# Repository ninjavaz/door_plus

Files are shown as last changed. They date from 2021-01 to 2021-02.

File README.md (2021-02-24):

Finished code for Door+ module. It's develop branch from private project repository.

Copyright (C) 2021 Door+ <d1n22@onet.pl><br>
This file is part of the Door+ project.<br>
The Door+ project can not be copied and/or distributed without the express<br>
permission of author Dominik Nuszkiewicz <d1n22@onet.pl>.<br>

# Door+

## Table of contents
* [General info](#general-info)
* [Technologies](#technologies)
* [Additional libraries](#libraries)
* [Components](#components)
* [Photos](#photos)

## General info
Door+ is automatic, contactless door module with IoT elements based on ESP32. It was made for engineering project on Warsaw University of Technology. It was built with MQTT server - https://hivemq.com
Physical module has a few functions. Main of these are:

1. Contactless opening and closing doors with ultrasonic motion sensor.
2. Counting people in the room - based on motion sensor too.
3. Remote communication provided by MQTT server and connected application of smartphone.

## Technologies
I used:
* https://hivemq.com as MQTT server
* MQTT Dash - app to send messages to MQTT
* PlatformIO IDE Ver 2.2.1
* Visual Studio Code Ver 1.52.1
* Tinkercad to create 3D printings

## Additional libraries
* PubSubClient 
* ESPAsyncWiFiManager
* ESPASyncWebServer
* Adafruit GFX Library
* AsyncTCP
* PubSubClient

## Components
Project was created with:
* Wemos D1 UNO R32 ESP32 WIFI Bluetooth
* Motion sensor HC-SR04 x2
* OLED monitor( SSD1306, 128x64px)
* Electric actuator LA10 500N 13mm/s, 12V, length max = 15 cm
* Power supply 12V for actuator
* Relays module with 2 canals 5V 10A/250VAC
* Power supply 9V for Wemos
* 3D Printings
* some typical cables and mini breadboard

## Photos

<p align="center">
  The main part with ESP32<br><br>
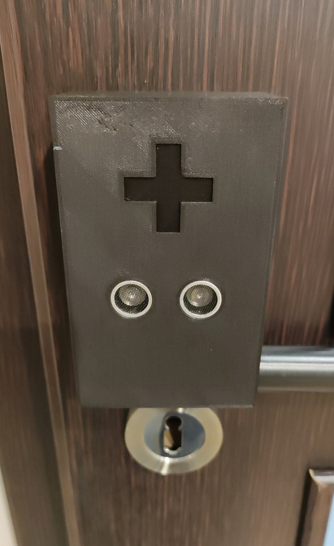
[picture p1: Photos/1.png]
  <br><br>
</p>
  
<p align="center">
  Back part with OLED<br><br>
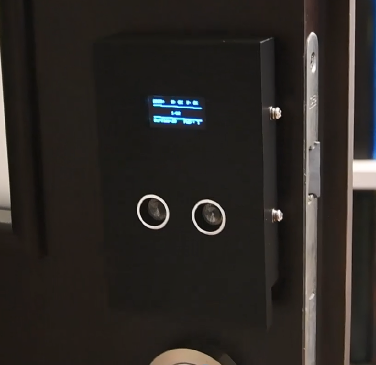
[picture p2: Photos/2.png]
  <br><br>
</p>  
  
<p align="center">
  Contactless open<br><br>
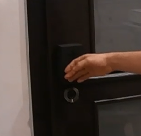
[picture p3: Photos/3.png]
  <br><br>
</p>
  
<p align="center">
  Actuator<br><br>
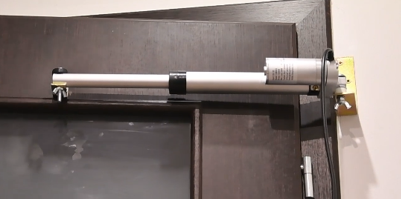
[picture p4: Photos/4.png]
  <br><br>
</p>

<p align="center">
  Closed in MQTT Dash<br><br>
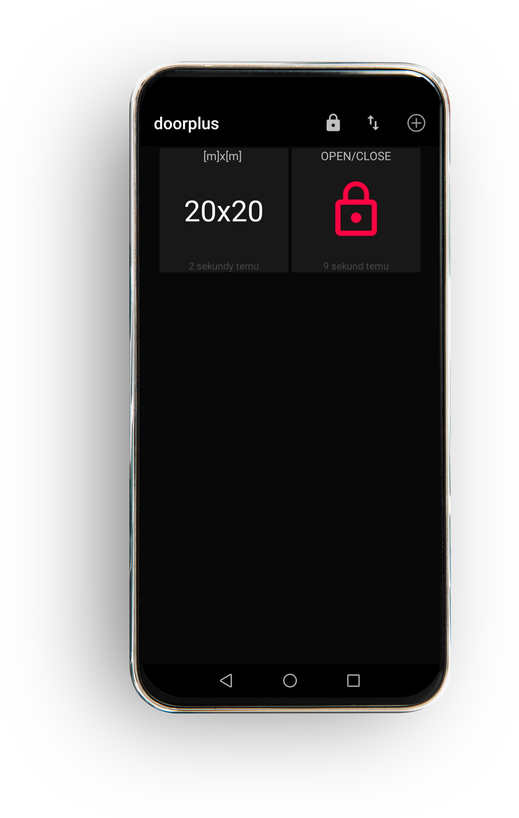
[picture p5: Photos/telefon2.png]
  <br><br>
</p>
  
<p align="center">
  Open in MQTT Dash<br><br>
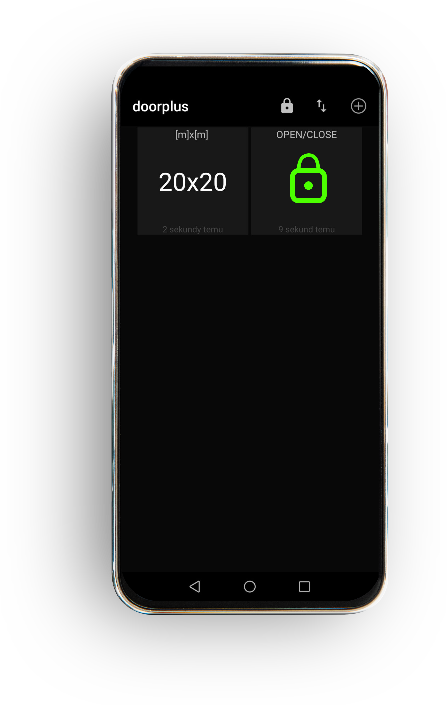
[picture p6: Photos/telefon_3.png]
  <br><br>
</p>  
  
<p align="center">
  Auto Wifi configuration<br><br>
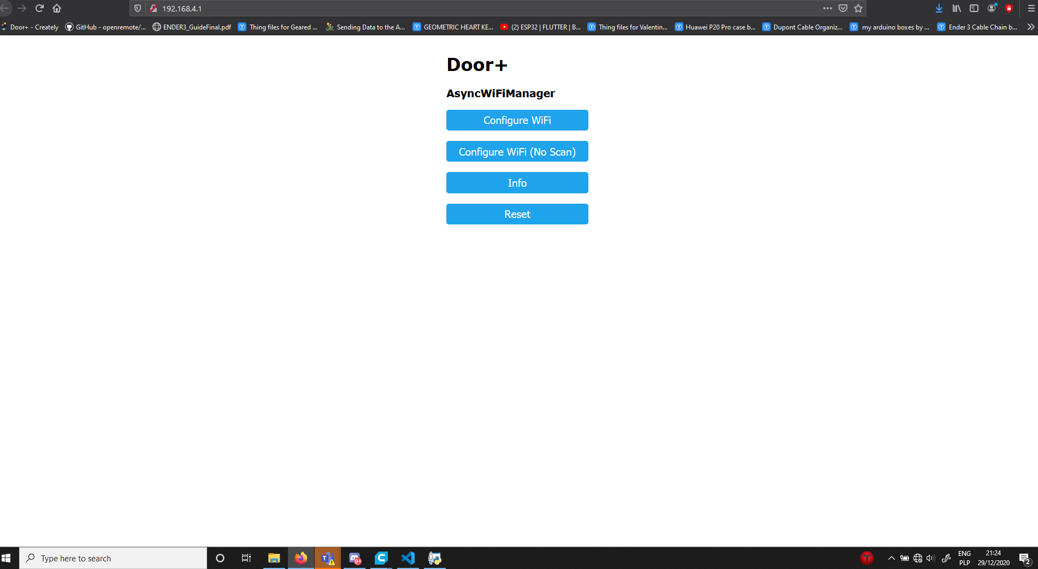
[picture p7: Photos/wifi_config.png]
  <br><br>
</p>

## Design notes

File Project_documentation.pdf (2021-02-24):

Politechnika Warszawska
Wydział Elektroniki i Technik Informacyjnych Kierunek: Elektronika

### Triple S Team

Krzysztof Banasiak
Konrad Krupski
Dominik Nuszkiewicz
Mateusz Szywała

### Projekt Door+

### Projekt inżynierski w ramach przedmiotów WPROJ oraz MEPI wykonany przez zespół Triple S Team

### Opiekun projektu: dr inż. Stanisław Stopiński

### Warszawa, Styczeń 2021

Zadanie projektowe z podziałem na wykonawców | 3
Wykorzystana terminologia | 3
Wprowadzenie i założenia wstępne | 4
Desk Research/Analiza danych zastanych | 4
Seniorzy | 4
Młodzież | 5
Osoby pracujące | 6
Studenci | 8
Mapa Emaptii | 9
Opis problemu projektowego | 11
Sformułowanie Problemu | 11
Wyzwanie projektowe | 11
Opis | 11
Persona | 12
Wnioski z empatyzacji | 12
Analiza SWOT | 13
Rozwiązanie | 15
Przeznaczenie: | 15
Zasada działania i realizowane funkcje: | 15
Właściwości eksploatacyjne | 16
Testowanie z użytkownikiem | 17
Projekt: | 17
Testowanie (plan): | 17
Testowanie: | 17
Podsumowanie: | 17
Dokumentacja techniczna | 18
Wykorzystane części | 18
Połączenie urządzenia | 20
Schemat obudowy | 21
Górna część pokrywy klamki | 21
Górna część pokrywy klamki | 22
Podstawa klamki | 23
Pokrywa przekaźnika | 24
Schemat blokowy kodu | 25
Instrukcja aplikacji do połączenia z MQTT | 26
Narzędzia | 30

Źródła | 30
Biblioteki | 31

### Zadanie projektowe z podziałem na wykonawców

### Wykorzystana terminologia

Konrad Krupski | Prezentacja, planowanie zadań
Dominik Nuszkiewicz | Część elektroniczna, planowanie działań związanych z częścią realizacyjną
Mateusz Szywała | Część elektroniczna, planowanie działań związanych z częścią realizacyjną
Krzysztof Banasiak | Udział w tworzeniu prezentacji oraz wspieranie przy części realizacyjnej
COVID-19 | Coronavirus Disease 2019, ostra choroba zakaźna układu oddechowego wywołana zakażeniem wirusem SARS-CoV-2.
MQTT | MQ Telemetry Transport, lekki protokół transmisji danych oparty o wzorzec publikacja/subskrypcja.
EPROM | Erasable Programmable Read-Only Memory, rodzaj pamięci cyfrowej w postaci układu scalonego przechowującego zawartość po odłączeniu zasilania.
TCP | Transmission Control Protocol, czyli protokół komunikacyjny stosowany do przesyłania danych między procesami uruchomionymi na różnych urządzeniach.
MATLAB | Program komputerowy będący interaktywnym środowiskiem do wykonywania obliczeń inżynierskich.
Wi-Fi | Protokół bezprzewodowych sieci oparty na standardach IEEE 802.11.
Websocket | Protokół internetowy zapewniający komunikację full-duplex poprzez TCP.

### Wprowadzenie i założenia wstępne

Celem naszego zespołu projektowego jest opracowanie rozwiązań problemów dotykających społeczeństwo. Pierwszymi czynnościami będzie przeprowadzenie badań dotyczących trudności, z którymi zmagają się osoby z każdej grupy społecznej i dokładne określenie problemu projektowego. W tym dokumencie zostanie zanotowane wszystko poczynając od tych właśnie badań do końcowego rozwiązania.

### Desk Research/Analiza danych zastanych

Seniorzy
OPIS CECH DEMOGRAFICZNO - SPOŁECZNYCH
Płeć | Mężczyźni, kobiety
Wiek | 60 +, 65 +
Dochody | Przeciętnie: 1648,75 zł
Status na rynku pracy (pracujący, niepracujący) | Niepracujący

Wykształcenie

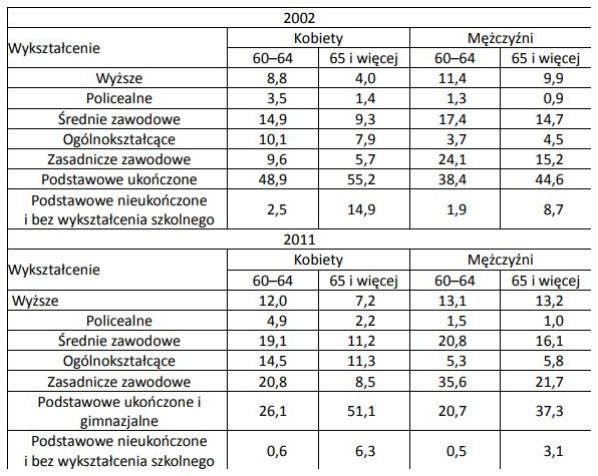
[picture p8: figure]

Miejsce zamieszkania | Warszawa, Kraków, Samotnie, dom starców, domy dziennego pobytu.

Młodzież

OPIS STYLU ŻYCIA
Czas wolny | Uczestnictwo w konkursach, uczęszczanie do bibliotek, uczestnictwo w projektach np. “Seniorzy w akcji”, Rady seniorów, zainteresowane funkcjonowaniem usług publicznych i polityką lokalną wobec osób starszych, zajmowanie się wnukami.
Problemy życiowe | Konflikty międzypokoleniowe, mieszkanie w samotności, słabo wyposażone mieszkania żyjących na wsi, pogorszenie stanu zdrowia, samotność, zagrożenie wykluczeniem społecznym, niepełnosprawność, nierówne i gorsze traktowanie.
Potrzeby | Potrzeby opiekuńcze związane z nie samodzielnością, gminy przyjazne seniorom, opieka zdrowotna, dostęp do leków.
Poglądy na życie | Z powodu wykluczenia społecznego zapominają o własnej starości, perspektywie śmierci.
Otwartość na nowe rzeczy | Niechęć do korzystania z nowych technologii (“Odsetek korzystających z tych najnowocześniejszych urządzeń wśród posiadających je w swoim gospodarstwie domowym waha się około połowy.”).

OPIS CECH DEMOGRAFICZNO - SPOŁECZNYCH

Płeć | Mężczyźni, kobiety
Wiek | Do 22 roku życia
Dochody | Średnio 450 zł miesięcznie pochodzące ze źródeł wymienionych w komórce poniżej
Status na rynku pracy (pracujący, niepracujący) | Różne źródła(praca wakacyjna, praca dorywcza, praktyki zawodowe, handel w internecie, praca stała, stypendia, kieszonkowe
Wykształcenie | Podstawowe, średnie
Miejsce zamieszkania | Polska

Osoby pracujące

OPIS STYLU ŻYCIA | Przynależność do różnych stowarzyszeń, organizacji, klubów, hobby. Styl życia ucznia lub studenta, nastawiony na rozwój samorealizację i pielęgnowanie relacji z przyjaciółmi, znajomymi itp.
Czas wolny | Spotkania z kolegami, przyjaciółmi, dziewczyną/chłopakiem, rówieśnikami, sport, gry komputerowe, surfowanie w internecie, dyskoteki, czytanie książek, telewizja, odpoczywanie
Problemy życiowe | Nie opisane
Potrzeby | Akceptacja wśród rówieśników, akceptacja rodziców i udane życie rodzinne, zdobycie ciekawej pracy, satysfakcjonująca sytuacja materialna, bycie użytecznym dla innych
Poglądy na życie | Najbardziej cenią sobie wartości takie jak: miłość i przyjaźń, udane życie rodzinne i ciekawą pracę w przyszłości.
Otwartość na nowe rzeczy | Bardzo otwarci

OPIS CECH DEMOGRAFICZNO - SPOŁECZNYCH

Płeć | Mężczyźni, kobiety
Wiek | Wiek produkcyjny, mężczyźni: 18-64 lata Kobiety: 18-59 lat
Dochody | Przeciętnie 4283,73 PLN
Status na rynku pracy (pracujący, niepracujący) | Pracujący

Wykształcenie

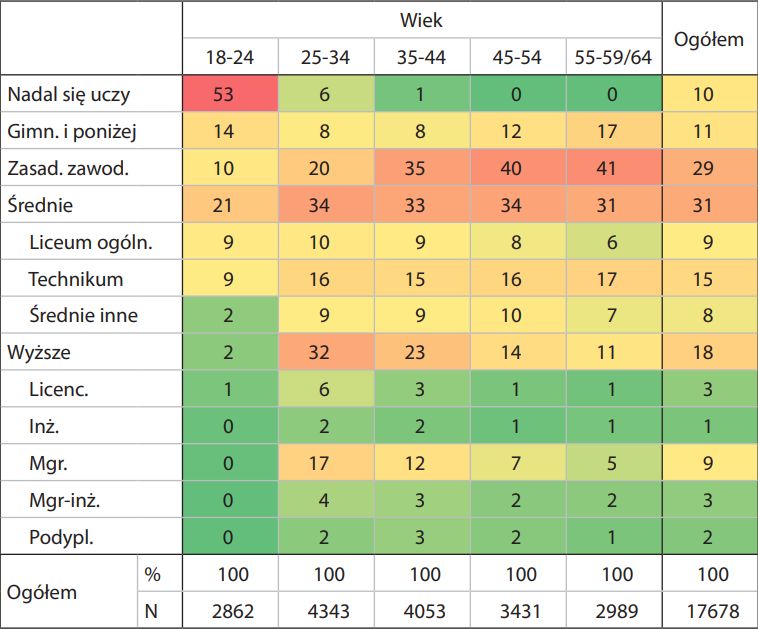
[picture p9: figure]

Miejsce zamieszkania | Dowolne
OPIS STYLU ŻYCIA | Osoby w wieku produkcyjnym prowadzą aktywne życie zawodowe oraz rodzinne.
Czas wolny | Oglądanie telewizji, angażowanie się w życie rodzinne, chodzenie na spacery, przeglądanie internetu, granie w gry, “wysypianie się”
Problemy życiowe | Stres, wypalenie zawodowe, brak czasu na spełnianie ambicji życia osobistego
Potrzeby | Potrzeba sensu, ciągły rozwój, wyróżnienie się, wpływ i sprawstwo
Poglądy na życie | Wiele z osób pracujących posiada odmienne poglądy na życie, w zależności od swoich doświadczeń. Na poglądy, oraz podejście do takich spraw jak życie w czasach PRLu składają się takie czynniki jak: zadowolenie z sytuacji materialnej, poglądy polityczne, wykształcenie, wiek, dochody oraz miejsce zamieszkania.
Otwartość na nowe rzeczy | Osoby w wieku produkcyjnym często są otwarte na nowe rzeczy, takie jak nowe możliwości zawodowe, nowe technologie oraz z czasem coraz bardziej poszerza swoje horyzonty.

Studenci

OPIS CECH DEMOGRAFICZNO - SPOŁECZNYCH

Płeć | Mężczyźni, kobiety
WIEK | 18-30
Dochody | Mediana 2000 zł
Status na rynku pracy (pracujący, niepracujący) | Praca wakacyjna, praca dorywcza, praktyki zawodowe, praca stała
Wykształcenie | średnie, wyższe
Miejsce zamieszkania | Polska
OPIS STYLU ŻYCIA | Przynależność do różnych stowarzyszeń, organizacji, klubów, hobby. W pracy nastawieni na zdobywanie doświadczenia bardziej niż korzyści materialnych.
Czas wolny | Spotkania z kolegami, przyjaciółmi, dziewczyną/chłopakiem, rówieśnikami, sport, gry komputerowe, surfowanie w internecie, dyskoteki, czytanie książek, Netflix, odpoczywanie
Problemy życiowe | Zmiany w życiu (często wyprowadzka do innego miasta z daleka od rodziny) Wśród studentów istnieje ogromne zapotrzebowanie na różnorodne komórki pomocy, a deficyt w tym zakresie dotyczy przeważającej liczby studentów. Problemy materialne.
Potrzeby | Akceptacja wśród rówieśników, akceptacja rodziców i udane życie rodzinne, zdobycie pierwszej pracy/ praktyk, satysfakcjonująca sytuacja materialna, czas na naukę
Poglądy na życie | -
Otwartość na nowe rzeczy | Bardzo otwarci

### Mapa Emaptii

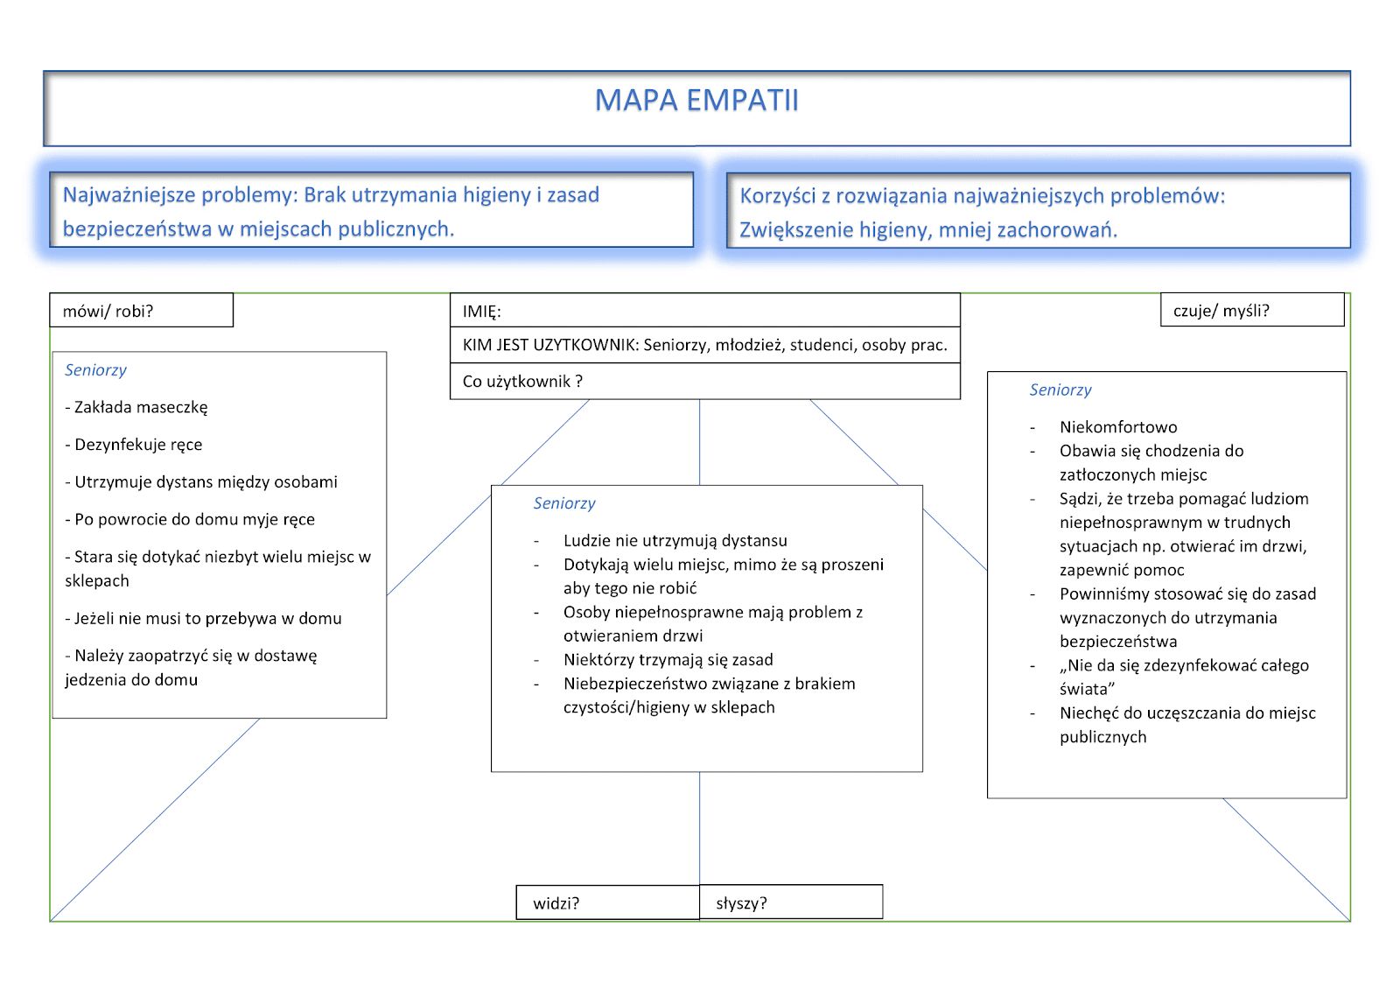
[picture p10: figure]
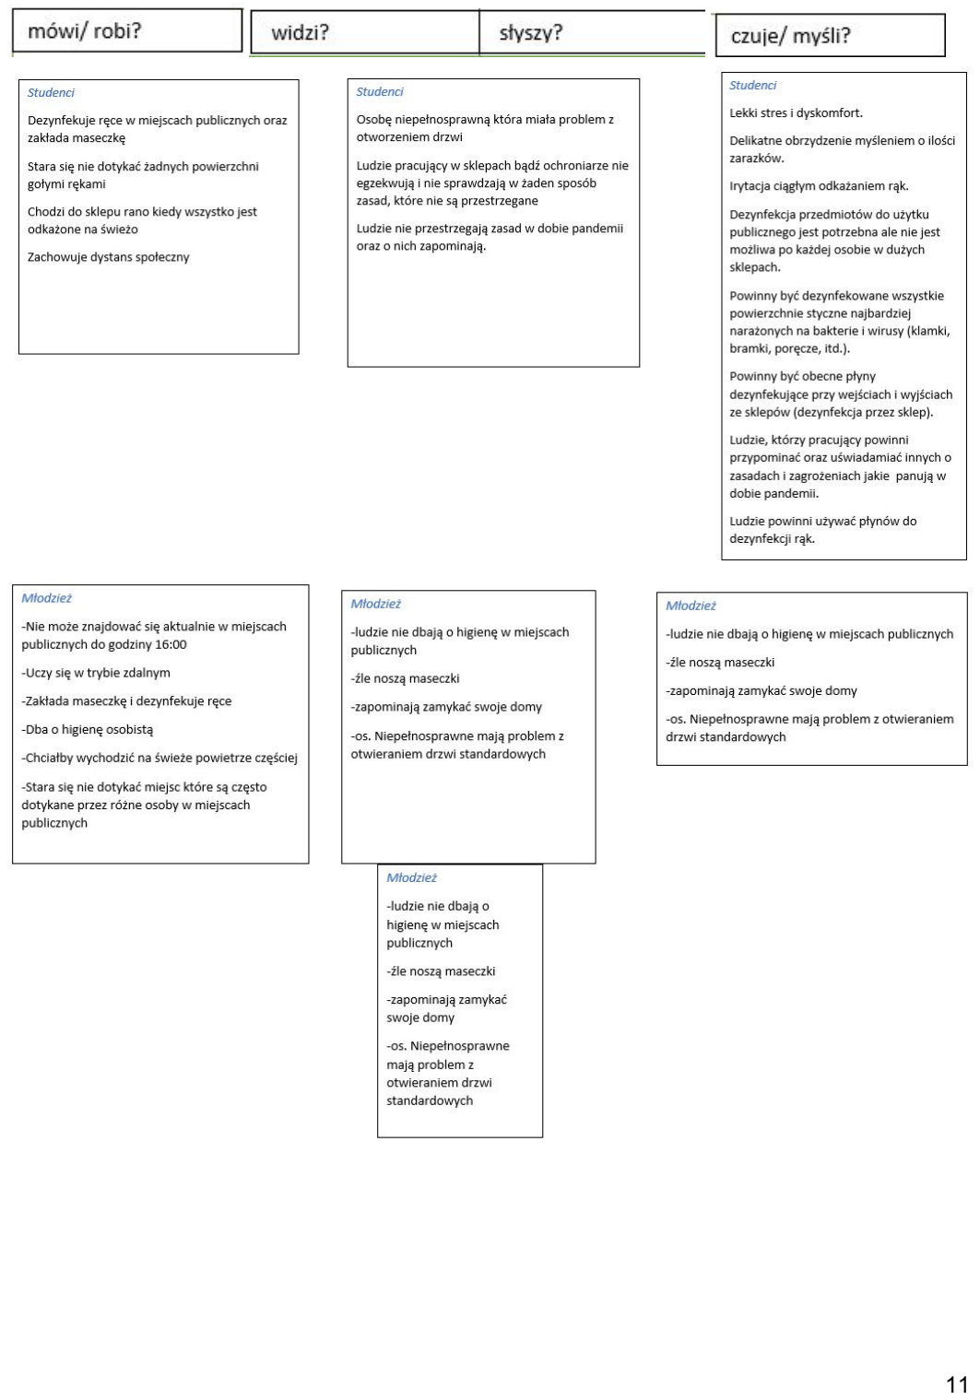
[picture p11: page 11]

### Opis problemu projektowego

Sformułowanie Problemu

Nie zachowywanie zasad higieny i bezpieczeństwa związanych z przebywaniem w miejscach publicznych.

Wyzwanie projektowe

Jak moglibyśmy zwiększyć poziom higieny i bezpieczeństwa w miejscach publicznych?
Jak moglibyśmy sprawić, aby rozwiązanie było odpowiednie dla wielu grup społecznych takich jak młodzież, seniorzy czy studenci?
Jak moglibyśmy sprawić, aby również osoby niepełnosprawne byłyby w stanie korzystać z tego rozwiązania?

Opis

Z powodu obecnej sytuacji panującej na świecie związanej z pandemią coraz ciężej jest zachować bezpieczeństwo oraz higienę w wielu miejscach a szczególnie tych, gdzie występują liczne zgromadzenia ludzi.
Ten problem nie tylko wynika z ignorancji, ale również z nieświadomości. Seniorzy jako grupa, która wykazuje się małą otwartością wobec nowoczesnych technologii rzadko korzysta z Internetu czy chociażby telewizji, dlatego niektóre informację mogą nie docierać do nich z taką łatwością jak do innych grup społecznych. Co więcej, jak już wcześniej zostało to wspomniane, grupy młodszych obywateli często ignorują zalecenia ekspertów.
Należy zauważyć, iż niemożliwym jest zdezynfekowanie całego świata. Z tego powodu w miejscach takich jak centra handlowe, hipermarkety czy sklepy spożywcze, pracownicy mają trudności utrzymać higienę na stopniu doskonałym, co jest kolejnym powodem wyżej wymienionego problemu.
Nie sposób pominąć, że nawet jeżeli chcemy przestrzegać zaleceń to czasami jest to niemożliwe. Dla przykładu ciężko jest nam ocenić, czy znajdujemy się w odległości przynajmniej półtorej metra od innych.
Dodatkowo, mimo obecnej sytuacji cały czas spotykamy się z sytuacją, że rodziny podczas robienia zakupów zabierają ze sobą dzieci. Skutkiem tego jest, że dotykają one wielu powierzchni bez powodu, zwiększając jednocześnie ryzyko zachorowania.

Persona

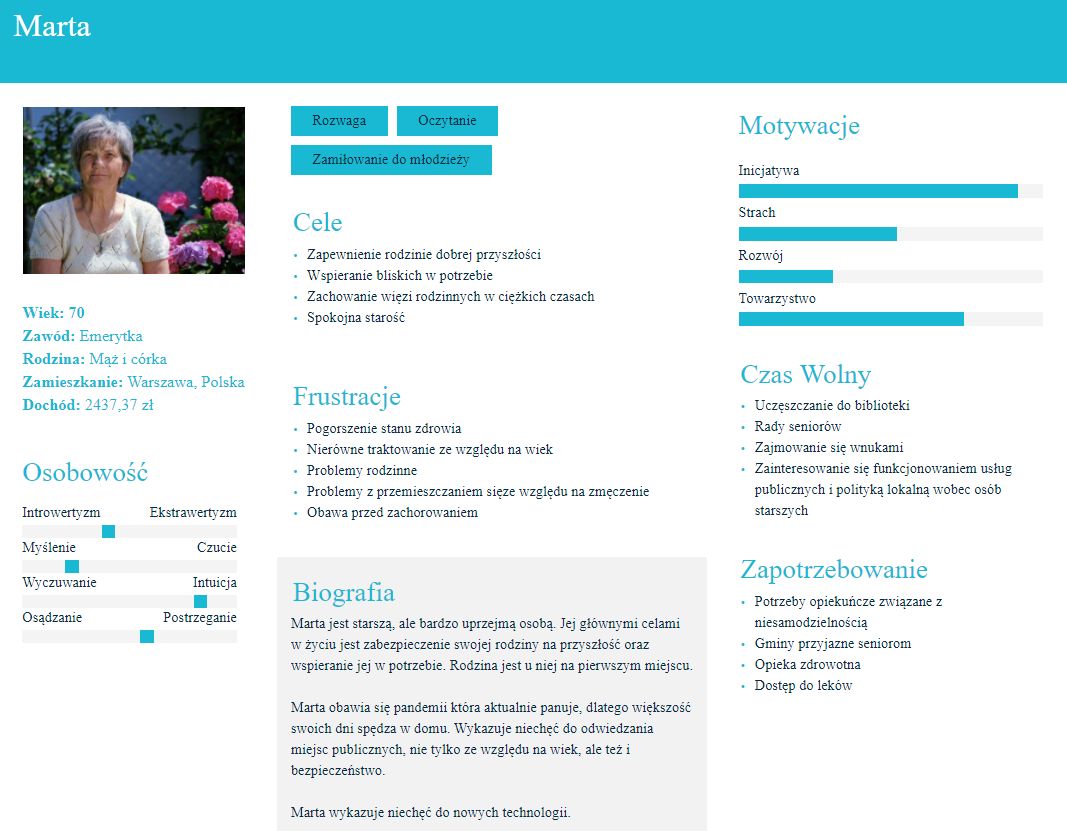
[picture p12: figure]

Wnioski z empatyzacji
Po przeprowadzeniu wywiadów z osobami z poszczególnych grup czyli seniorów, osób pracujących, młodzieży oraz studentów doszliśmy do wniosku, że:
- Problemy z higieną istnieją wśród wszystkich grup demograficznych oraz społecznych
- Dla wielu osób przestrzeganie zasad higieny stanowi ważny element do osiągnięcia poczucia bezpieczeństwa oraz komfortu psychicznego
- Wiele osób podchodzi do tematu higieny poważnie ze względu na bezpieczeństwo swoje oraz innych
- Seniorzy obawiają się uczęszczania do miejsc publicznych dlatego można zauważyć, że problem rzeczywiście istnieje
- Zachowania związane z brakiem przestrzegania zasad pojawiają się rutynowo wśród każdej z grup społecznych co wynika z mapy empatii.

Analiza SWOT

Wewnętrzne MOCNE STRONY ● Bardzo dobrze współpracujemy oraz uzupełniamy swoje słabości ● Młody i kreatywny zespół ● Dobrze operujemy oraz odnajdujemy się w nowoczesnych technologiach ● Dobra organizacja ● Otwartość na zmiany, dzięki czemu łatwo przyswajamy zmiany związane z projektami ● Możliwość pomocy od wykwalifikowanych osób ● Możliwość korzystania z specjalistycznego sprzętu na wydziale ● Instytucja udostępnia nam bardzo dużo programów oraz licencji np. MATLAB oraz Arduiono, które mogą zostać wykorzystane do realizacji pomysłów ● Nowoczesne wyposażenie z uczelni ● Mechanizm otwierania drzwi działa nawet gdy brakuje zasilania ● Wysokie kwalifikacje ● Wiele możliwości zastosowań rozwiązania: bezpieczeństwo, higiena ● Prosta zasada działania ● Przystępność rozwiązania dla każdej grupy społecznej ● Łatwa rozbudowa urządzenia z rozwiązania zależnie od potrzeb

SŁABE STRONY
- Niedoświadczeni w tematach projektowych
- Brak umiejętności do
wykorzystania zasobów
instytucji w całkowitym stopniu
- Mamy problemy z
podejmowaniem decyzji
- Przecenianie swoich możliwości
- Czasami brakuje zasobów do zmian i są one niemożliwe
- Niewielkie zasoby finansowe
- Rozwiązanie jest uzależnione od zasilania
- Możliwość awarii czujnika ruchu co powoduje problem z otwieraniem drzwi
- Brak długofalowej strategii
- Wykończenie projektu może być kosztowne ze względu na ilość funkcji, które zawiera

Zewnętrzne | SZANSE | ZAGROŻENIA
Czynniki społeczne ● Ułatwione zbieranie feedbacku poprzez Internet ● Możliwość zbierania informacji od osób starszych na wydziale poprzez grupy/social media. ● Społeczeństwo często spędza czas w Internecie, dlatego łatwo można zareklamować nowe produkty ● Możliwość organizacji darmowych szkoleń w zakresie technologii połączonych z nauką obsługi urządzenia | Czynniki społeczne ● Niektóre grupy społeczne mają ograniczony dostęp do technologii
Czynniki gospodarcze ● Młode firmy przyciągają uwagę swoją innowacyjnością ● Dofinansowania dla nowych, innowacyjnych firm ● Przyjazne prawa podatkowe dla technologicznych firm ● Inkubatory innowacyjności | Czynniki gospodarcze ● Firmy bardziej doświadczone i działające na większą skalę ● Małe zainteresowanie inwestorów ● Brak środków finansowych
Czynniki prawno-administracyjne ● Nasze rozwiązanie jest związane z obecnym problemem pandemii ● Rozwiązanie jest uniwersalne oraz ma wiele dodatkowych zastosowań. ● Wspiera przestrzeganie prawa (zgodne z prawem) | Czynniki prawno-administracyjne ● Kończenie się licencji na programy oraz sprzęt z uczelni ● Większe firmy wykupują te, które bankrutują i zmieniają warunki licencji na programy oraz sprzęt
Czynniki technologiczne ● Szybsza komunikacja ● Możliwość pracy zdalnej ● Wraz z rozwojem technologii rośnie zaawansowanie naszego produktu ● Nasze rozwiązanie dotyczy Internetu rzeczy, bardzo popularnej i prężenie rozwijającej się koncepcji. | Czynniki technologiczne ● Problemy techniczne ograniczają komunikację ● Technologia bywa zawodna, dlatego poleganie na niej może ograniczyć działalność firmy

### Rozwiązanie

Nazwa urządzenia: Door+

Przeznaczenie:

Automatyczne otwieranie i zamykanie drzwi, pomiar wartości takich jak: temperatura, ilość osób w pomieszczeniu oraz poziom zagrożenia zakażeniem. Urządzenie jest przeznaczone do zapewnienia jak najwyższych standardów higieny oraz bezpieczeństwa. Jego celem jest wspieranie branży detalicznej w sposób zapewniający bezpieczeństwo prowadzonego biznesu. Dodatkowym przeznaczeniem urządzenia jest zabezpieczenie przed kradzieżą.

Zasada działania i realizowane funkcje:

Użytkownik korzystający z door+ będzie badany pod względem przestrzegania higieny oraz zasad bezpieczeństwa. Urządzenie będzie wyświetlało komunikaty dotyczące tych właśnie zasad. Door+ informuje o ilości osób w pomieszczeniu oraz oblicza, na podstawie algorytmu maksymalną ich ilość, która jest zgodna ze standardami związanymi z COVID-19. Użytkownik za pomocą aplikacji MQTT Dasz na system Android jest w stanie skonfigurować urządzenie. Połączenie poprzez protokół MQTT jest możliwe dzięki Wi-Fi. Dane dotyczące połączenia są przechowywane na pamięci EEPROM.

Działanie protokołu MQTT w projekcie Door+
Urządzenie mobilne z system Android wysyła informacje do brokera MQTT pod adresem broker.hivemq.com, portem TCP: 1883, Websocketem: 8000, który następnie przekazuje tą informację do urządzenia Door+. Urządzenie po automatycznym zasubskrybowaniu tematu obiera tą informacje i koduje ją poprzez zmianę wartości zmiennej i zapisuje ją do pamięci EEPROM.
System obsługujący urządzenie jest napisany w języku C++ oraz wymaga połączenia z płytką ESP 32.

### Właściwości eksploatacyjne

Urządzenie pracuje stacjonarnie, zasilane napięciem 12V i prądem 2.5A. Użytkownik ma możliwość zdalnej konfiguracji urządzenia po wcześniejszym połączeniu go z siecią bezprzewodową. Konfiguracja jest wykonywana poprzez aplikację MQTT Dash. Informację dotyczące sieci bezprzewodowej są zapisywane w pamięci EEPROM z możliwością ich późniejszego wczytania. Wyświetlacz OLED jest połączony z płytką ESP32, dlatego nie potrzebuje zewnętrznego zasilania.

### Testowanie z użytkownikiem

Projekt:

Door+ jest urządzeniem w postaci drzwi. Użytkownik podchodząc do drzwi powinien poczekać aż one się otworzą i przez nie przejść. Obok door+ będzie wisiał ekran pokazują, ile osób aktualnie może znajdować się w pomieszczeniu oraz czy można bezpiecznie wejść do środka. Jeżeli użytkownik będzie chciał zmienić dozwoloną ilość osób w pomieszczeniu będzie mógł to zrobić za pomocą aplikacji w telefonie.

Testowanie (plan):

Eksperyment urządzenia będzie przeprowadzony w środowisku domowym z uwagi na okoliczności związane z COVID-19. Domownicy zostaną poproszeni o skorzystanie z urządzenia bez wcześniejszego poinformowania o jego zasadzie działania. Osoby odpowiedzialne za projekt będą notować, czy pojawiły się jakieś problemy ze skorzystaniem z urządzenia i odczytaniem informacji na monitorze. Następnie domownicy zostaną poproszeni o użycie aplikacji MQTT Dash do zmienienia danych o wielkości pomieszczenia w door+. Projektanci będą, w razie potrzeby, pomagali z tym krokiem. Na zakończenie zostaną zebrane opinie dotyczące urządzenia i ewentualne pomysły na poprawienie go.

Testowanie:

Kwestia dotycząca odczytania informacji o pomieszczeniu i skorzystania z door+ przebiegła bez większych problemów, użytkownicy nie mieli trudności z domyśleniem się jak wszystko działa. Niestety ekran, który został użyty w projekcie jest dosyć mały, dlatego pojawiły się pewne trudności z odczytaniem informacji z daleka natomiast informacja, która była wyświetlana okazała się czytelna i zrozumiała dla każdego. Niestety, podczas testowania aplikacji na urządzenia mobilne projektanci musieli pomagać użytkownikom z rekonfiguracją door+. Tylko jedna z trzech osób poradziła sobie z tym krokiem.

Podsumowanie:

Testowanie przebiegło pomyślnie oraz znaczna ilość problemów została ujawniona. Użytkownicy byli zadowoleni z urządzenia.

### Dokumentacja techniczna

Wykorzystane części

Lp. | Opis | Funkcja/Wyjaśnienie | Szt .
1 | Wemos D1 UNO R32 na ESP32 WIFI Bluetooth | Część sprawująca połączenie czujnika ruchu, wyświetlacza OLED, siłownika, elektromagnesu ciągnącego oraz modułów przekaźników. Płytka idealnie nadaje się do połączenia z Wi-Fi oraz zawiera odpowiednią ilość portów do podłączenia siłownika, czujników ruchu, wyświetlacza OLED. Dodatkowo zasilana jest odpowiednim napięciem potrzebnym do realizacji wszystkich funkcji bez niepotrzebnego zużycia energii. | 1
2 | Czujnik ruchu HC-SR04 | Wykrywanie ruchu osoby podchodzącej oraz odchodzącej od drzwi. Czujnik wykrywający ruch w trzech wymiarach za przystępną cenę. Odpowiednio wykrywa ruch w niedużych odległościach. | 2
3 | Wyświetlacz OLED (128 x 64) | Prezentacja informacji dotyczących bezpieczeństwa oraz zasad higieny, wersji oraz aktualnego stanu systemu sprawującego kontrolę nad urządzeniem. Wyświetlacz nie jest odpowiednich rozmiarów, ale został wybrany ze względu na przystępną cenę, okazał się wystarczający do prezentacji funkcji, które urządzenie ma spełniać. | 1
4 | Siłownik elektryczny LA10 500N 13mm/s 12V - wysuw 15cm | Wykonywanie pracy w celu zamknięcia oraz otwarcia drzwi. Ten siłownik posiada odpowiednią siłę ciągu oraz pobiera on energię tylko podczas otwierania drzwi. Napięcie potrzebne do pracy jest również odpowiednie do płytki, która ma go obsłużyć. | 1
5 | Elektromagnes ciągnący 12V 0,6kg | Blokada drzwi podczas gdy są zamknięte oraz odblokowanie po otrzymaniu sygnału do otwarcia. Model tego elektromagnesu pracuje pod odpowiednim napięciem oraz nie wymaga dużego prądu, dodatkowo posiada łatwą instalację, dlatego został on wybrany. | 1

6 | Zasilacz impulsowy 12V/2,5A - wtyk DC 5,5/2,5mm | Zasilanie płytki ESP32 oraz elementów podłączonych do niej. Zasilacz został wybrany ze względu na cenę oraz odpowiednie parametry, które są dobre dla każdego elementu. | 1
7 | Moduł przekaźników 2 kanały - styki 10A/250VAC - cewka 5V | Sterowanie elementami wykonawczymi za pomocą systemu uruchomieniowego oraz portów mikrokontrolera. Moduł został wybrany ze względu na cenę oraz wystarczającą ilość kanałów, służących do podłączenia | 1
8 | Moduł przekaźnika 1 kanał z optoizolacją - styki 10A/250VAC cewka 5V | Sterowanie elementami wykonawczymi za pomocą systemu uruchomieniowego oraz portów mikrokontrolera. Moduł został wybrany ze względu na cenę oraz wystarczającą ilość kanałów, służących do podłączenia urządzenia a także dodatkową izolację zapewniającą odpowiednią pracę urządzenia. | 1
9 | Koszyk na 6 baterii typu AA (R6) - 2x3 | Zasilanie niestacjonarne w razie awarii lub zaniku energii elektrycznej z sieci. Do zasilania 12V w razie awarii potrzebna była odpowiednia ilość baterii, dlatego ten koszyk jest odpowiedni. | 1

Połączenie urządzenia

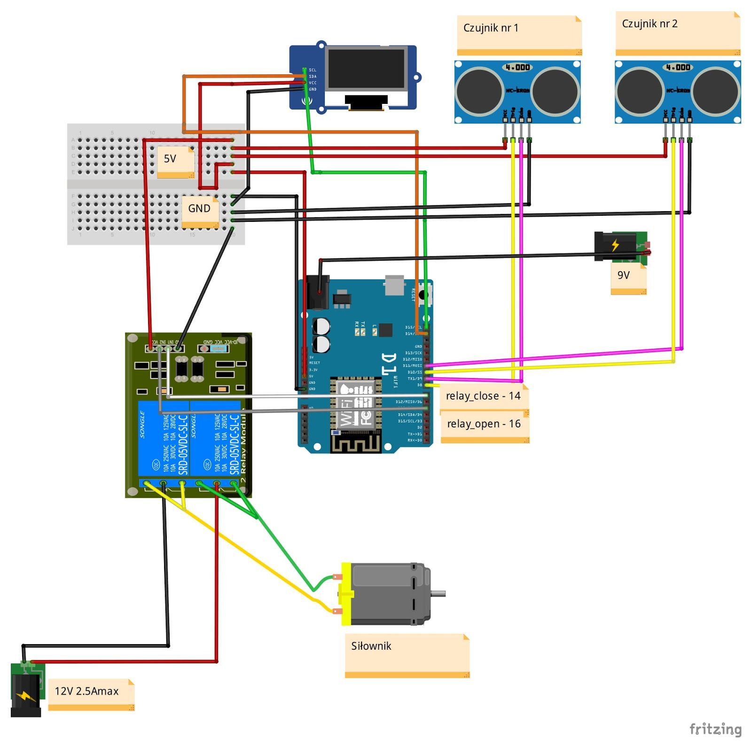
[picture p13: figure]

Schemat urządzenia

### Schemat obudowy

Górna część pokrywy klamki

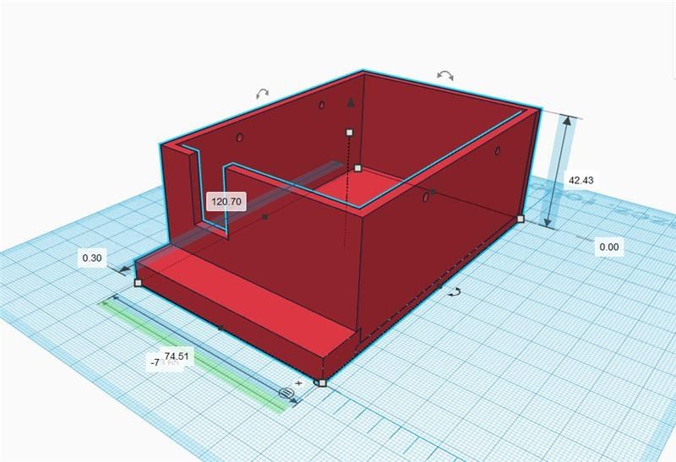
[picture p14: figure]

Górna część pokrywy klamki

Górna część pokrywy klamki

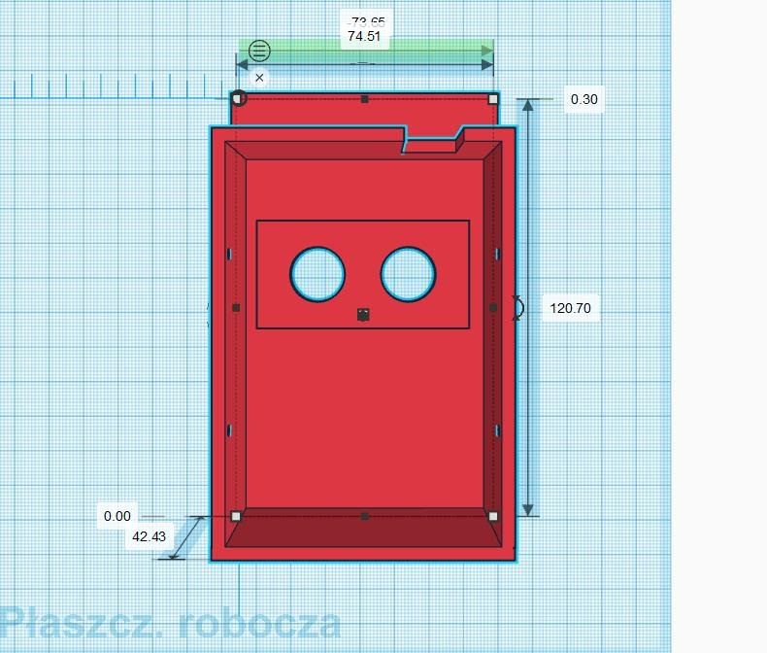
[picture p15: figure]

Górna część pokrywy klamki

Podstawa klamki

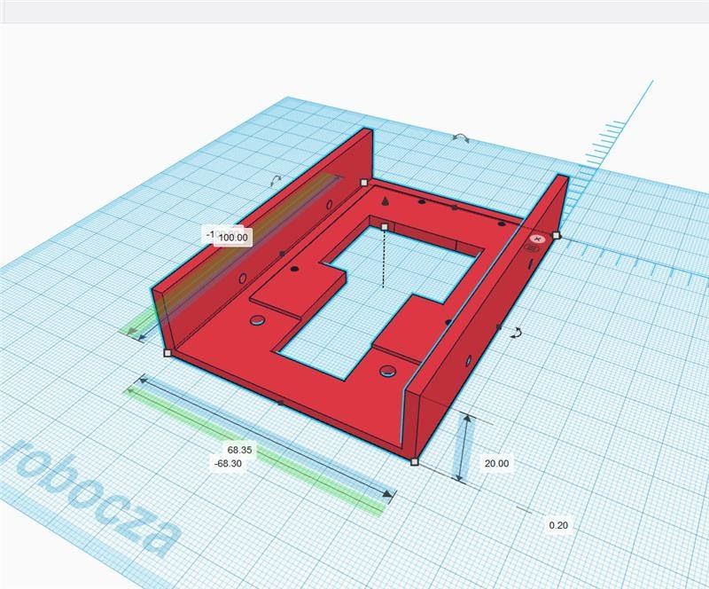
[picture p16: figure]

Podstawa klamki

Pokrywa przekaźnika

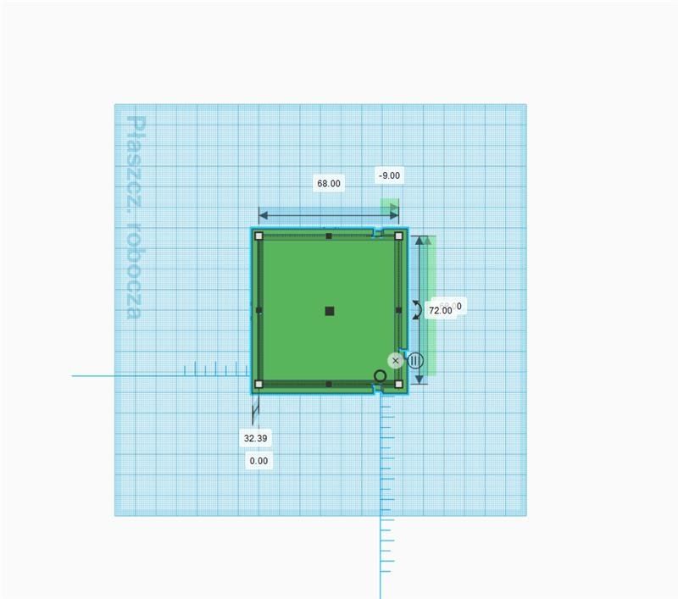
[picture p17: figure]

Pokrywa przekaźnika

Schemat blokowy kodu

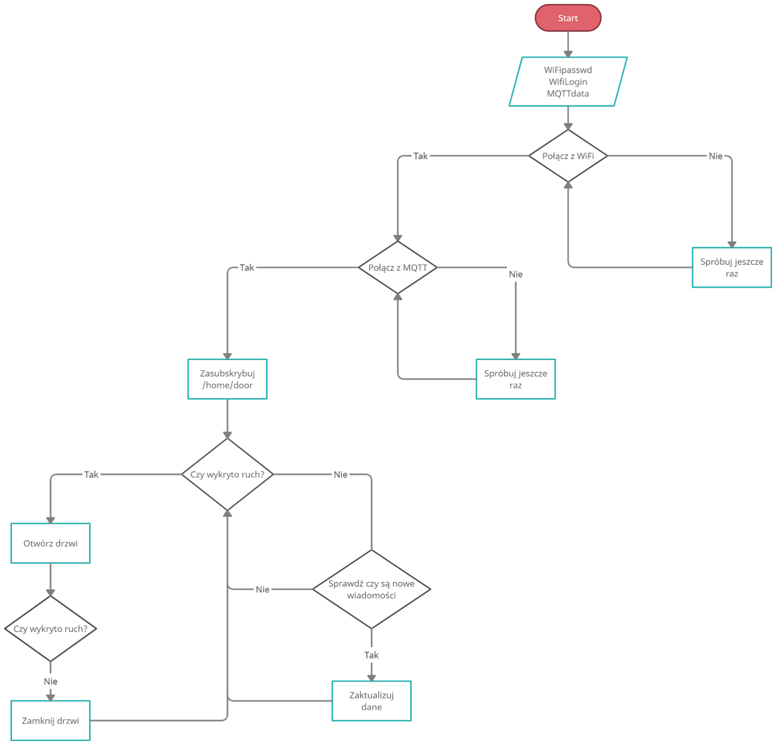
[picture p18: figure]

Instrukcja aplikacji do połączenia z MQTT

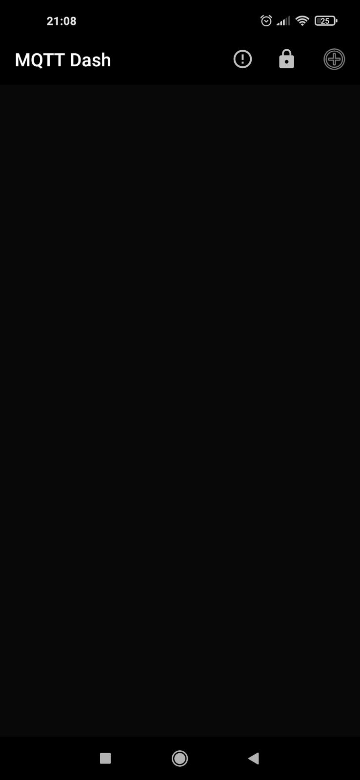
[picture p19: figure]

Interfejs aplikacji po uruchomieniu w środowisku Android.
Po uruchomieniu aplikacji należy dodać nowy serwer MQTT poprzez kliknięcie ikonki plusa w prawym górnym rogu interfejsu graficznego.

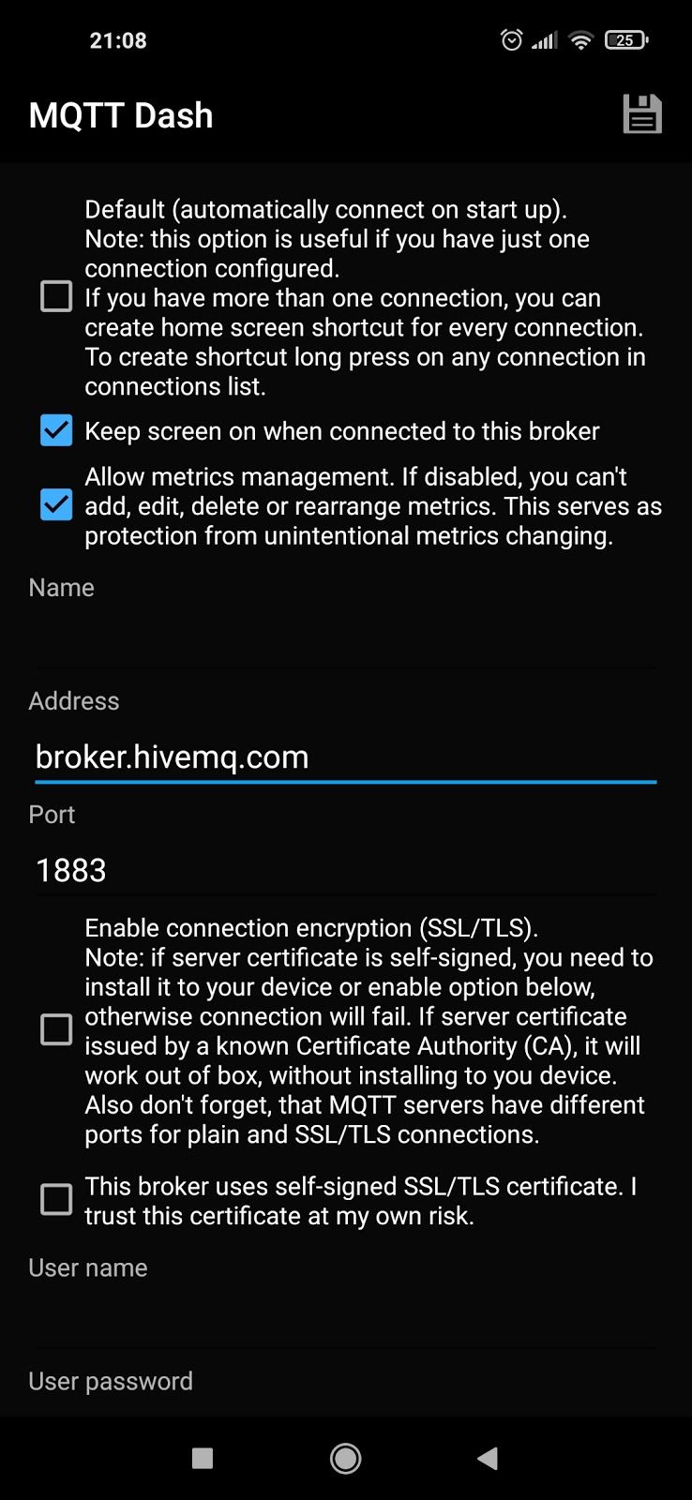
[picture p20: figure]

Interfejs dodawania serwera MQTT
W celu połączenia się z serwerem należy wpisać Address: broker.hivemq.com oraz Port:1883, a następnie zapisać serwer poprzez kliknięcie ikonki w prawym górnym rogu.

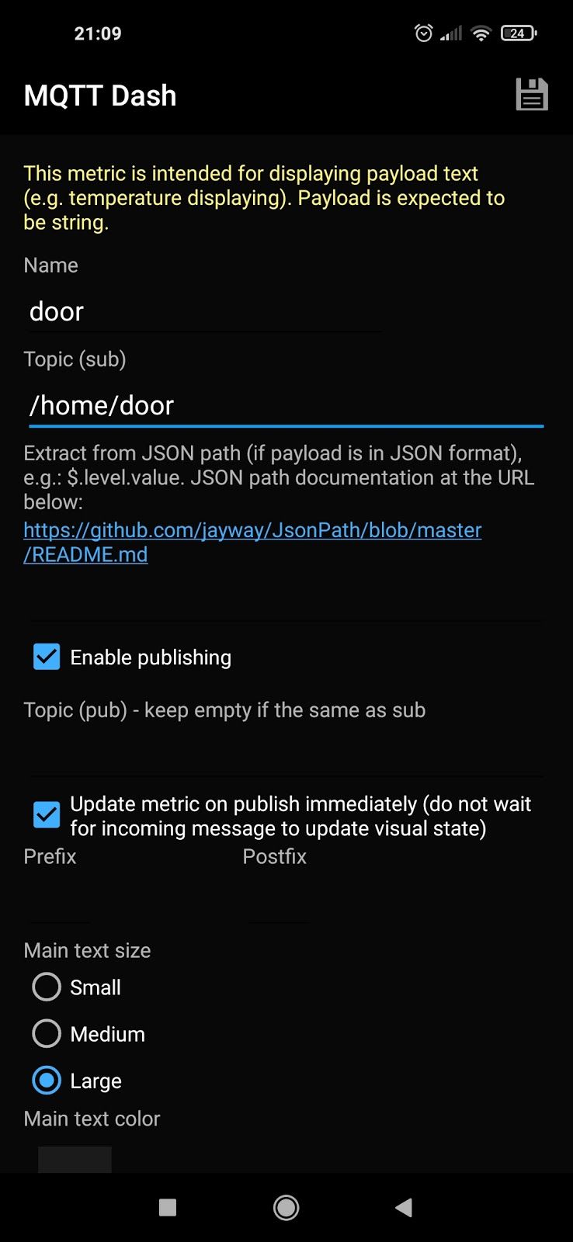
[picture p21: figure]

Interfejs dodawania subskrypcji
W celu subskrybowania tematu należy wpisać Topic(sub): /home/door oraz zapisać zmiany za pomocą ikonki w prawym górnym rogu.

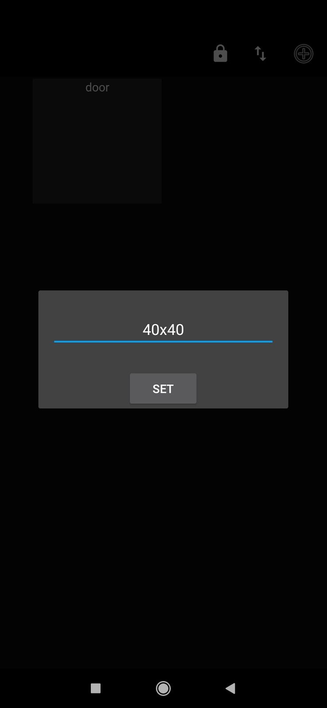
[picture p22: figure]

Komenda do aktualizacji danych urządzenia
W celu aktualizacji powierzchni, którą urządzenie ma pokrywać należy wysłać sygnał w formacie [liczba]x[liczba] używając wcześniej utworzonego połączenia.

Narzędzia

Visual Studio Code Version 1.52.1 (user setup) Rozszerzenia:
PlatformIO IDE Version 2.2.1
C/C++ Version 1.1.3
Github
Trello
MQTT Dash
TinkerCad

Źródła

Wemos D1 UNO R32 na ESP32 WIFI Bluetooth https://elektroweb.pl/esp32/610-wemos-d1-uno-r3-na-esp32-wifi-bluetooth-arduino.html

Czujnik ruchu HC-SR04
https://botland.store/ultrasonic-distance-sensors/1420-ultrasonic-distance-sensor-hc-sr04-2-200c m-5903351241366.html (https://botland.store/ultrasonic-distance-sensors/1420-ultrasonic-distance-sensor-hc-sr04-2-200cm-5903351241366.html)

Wyświetlacz OLED (128 x 64) https://allegro.pl/oferta/wyswietlacz-oled-0-96-ssd1306-blue-arduino-spi-i2c-7636893024

Siłownik elektryczny LA10 500N 13mm/s 12V - wysuw 15cm https://botland.com.pl/silowniki-liniowe/17096-silownik-elektryczny-la10-500n-13mms-12v-wy suw-15cm.html (https://botland.com.pl/silowniki-liniowe/17096-silownik-elektryczny-la10-500n-13mms-12v-wysuw-15cm.html)
Elektromagnes ciągnący 12V 0,6kg https://botland.com.pl/elektromagnesy/17758-elektromagnes-ciagnacy-12v-06kg.html Zasilacz impulsowy 12V/2,5A - wtyk DC 5,5/2,5mm https://botland.com.pl/zasilacze-dogniazdkowe/5043-zasilacz-impulsowy-12v25a-wtyk-dc-5525 mm-5902270703290.html (https://botland.com.pl/zasilacze-dogniazdkowe/5043-zasilacz-impulsowy-12v25a-wtyk-dc-5525mm-5902270703290.html)
Moduł przekaźników 2 kanały - styki 10A/250VAC - cewka 5V https://botland.com.pl/przekazniki/2043-modul-przekaznikow-2-kanaly-styki-10a250vac-cewka-5v.html (https://botland.com.pl/przekazniki/2043-modul-przekaznikow-2-kanaly-styki-10a250vac-cewka-5v.html)
Moduł przekaźnika 1 kanał z optoizolacją - styki 10A/250VAC cewka 5V https://botland.com.pl/przekazniki/1997-modul-przekaznika-1-kanal-z-optoizolacja-styki-10a250 vac-cewka-5v.html (https://botland.com.pl/przekazniki/1997-modul-przekaznika-1-kanal-z-optoizolacja-styki-10a250vac-cewka-5v.html)

Koszyk na 6 baterii typu AA (R6) - 2x3 https://botland.com.pl/koszyki-na-baterie/2430-koszyk-na-6-baterii-typu-aa-r6-2x3.html

Biblioteki

Arduino.h
https://github.com/arduino/ArduinoCore-avr/blob/master/cores/arduino/Arduino.h Opis:
Domyślna biblioteka Arduino.

WiFi.h
https://github.com/espressif/arduino-esp32/blob/master/libraries/WiFi/src/WiFi.h Opis:
Biblioteka umożliwiająca połączenie płytki Arduino z WiFi.

PubSubClient.h
https://github.com/knolleary/pubsubclient
Opis:
Biblioteka umożliwiająca na korzystanie z protokołu MQTT na płytce ESP.

Wire.h
https://github.com/esp8266/Arduino/blob/master/libraries/Wire/Wire.h Opis:
Biblioteka niskopoziomowych funkcji wyświetlacza SSD1306

Adafruit_SSD1306.h
https://github.com/adafruit/Adafruit_SSD1306
Opis:
Biblioteka dla monochromatycznych ekranów OLED, oparta na sterownikach SSD1306

Adafruit_GFX.h
https://github.com/adafruit/Adafruit-GFX-Library
Opis:
Główna biblioteka dla wyświetlaczy SSD1306 zapewniająca funkcje graficzne.

MQTT
https://randomnerdtutorials.com/esp32-mqtt-publish-subscribe-arduino-ide/

Ekran OLED
https://studia.elka.pw.edu.pl/f-en/20Z/103A-ELxxx-ISP-WPROJ/priv/

Persona
https://xtensio.com/

Strona do modelowania 3D:
https://www.tinkercad.com/

Strona serwera MQTT:
https://www.hivemq.com/public-mqtt-broker/

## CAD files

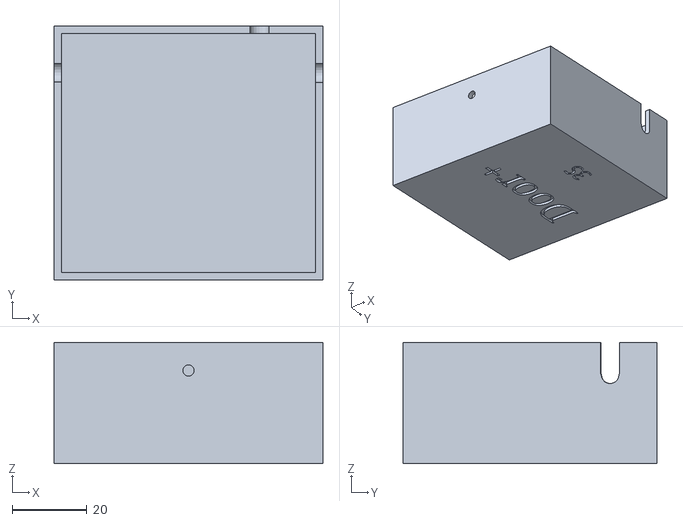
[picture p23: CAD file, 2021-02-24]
3d_projects/nakrywka_przekazniki.stl
72.0 x 68.0 x 32.4

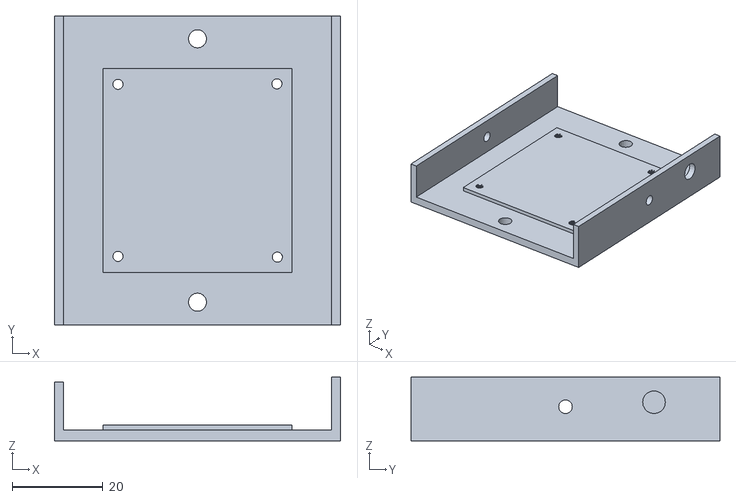
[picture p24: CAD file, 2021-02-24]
3d_projects/podstawa_przekazniki.stl
63.0 x 68.0 x 14.0

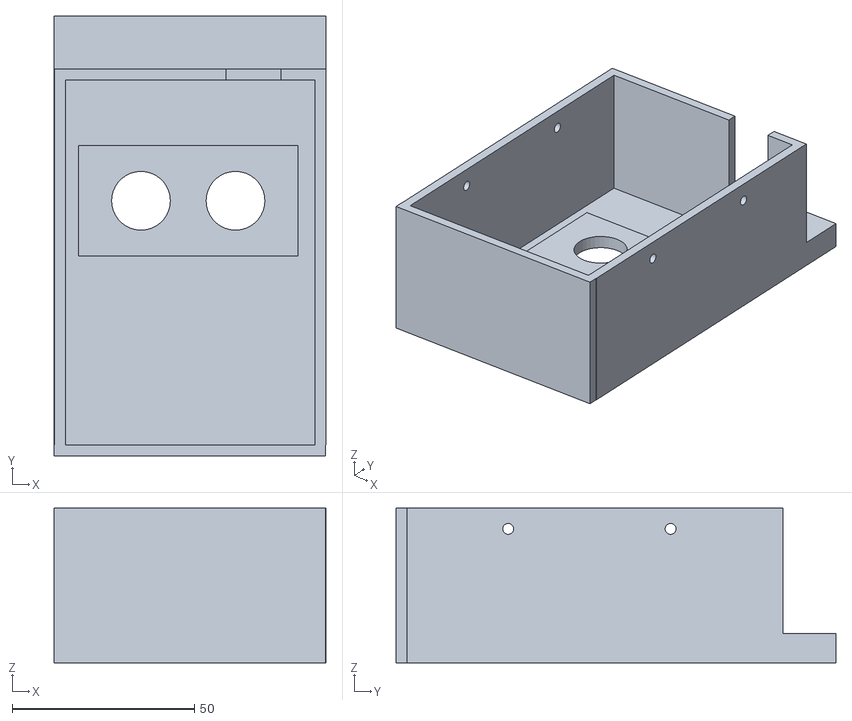
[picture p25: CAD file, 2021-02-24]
3d_projects/nakrywka_klamka.stl
74.5 x 120.7 x 42.4

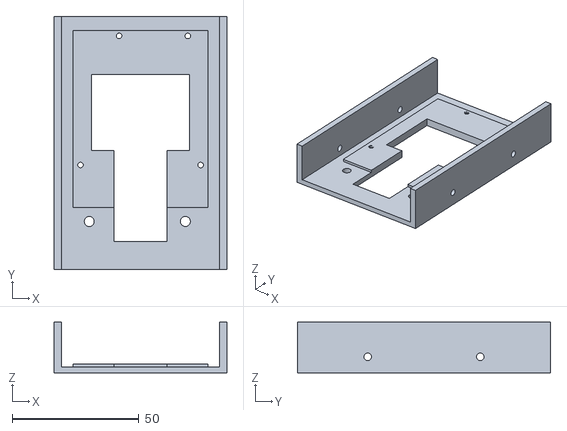
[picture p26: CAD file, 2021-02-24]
3d_projects/podstawa_klamka.stl
68.3 x 100.0 x 20.0

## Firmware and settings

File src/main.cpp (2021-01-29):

/* Door+ software made by 3S Team 
// Author: Dominik Nuszkiewicz
//
*/
//Dla nazw funkcji uzywamy podlogi _, dla zmiennych zaczynamy od duzych liter

#include <Arduino.h>

//blibloteki do komunikacji sieciowej
#include <WiFi.h>
#include <PubSubClient.h>



//do oledu
#include <Wire.h>
// Biblioteka niskopoziomowych funkcji wyświetlacza SSD1306.
#include <Adafruit_SSD1306.h>
// Biblioteka wysokopoziomowych funkcji dla różnych wyświetlaczy.
#include <Adafruit_GFX.h>


const int WIDTH = 128; // Szerokość wyświetlacza w pikselach
const int HEIGHT  = 64;  // Wysokość wyświetlacza w pikselach

// Stworzenie obiektu odpowiadającego naszemu wyświetlaczowi.
Adafruit_SSD1306 ekranik(WIDTH, HEIGHT, &Wire, -1);
//do oledu end

//Zmienne globalne

//Odlegosci czujników od najblizszego przedmiotu
float distance1; //odleglosc najbliżeszego przedmiotu od czujnika nr 1
float distance2; //odleglosc najbliżeszego przedmiotu od czujnika nr 2

int default_distance=5.00; //odległość w jakiej czujnik wykrywa ruch(domyślnie=5cm)



String surface;
int surface_room;

int axis = 0; //kąt otwarcia
bool isOpen; 
String topic1 = ""; //Variables for mqtt topics
String topic2 = ""; 


//CONFIG MODE START(Wifi manager)

////biblioteki
#include <ESPAsyncWebServer.h>     //Local WebServer used to serve the configuration portal
#include <ESPAsyncWiFiManager.h>          //https://github.com/tzapu/WiFiManager WiFi Configuration Magic

AsyncWebServer server(80); //do wifi managera
DNSServer dns;

AsyncWiFiManager wifiManager(&server,&dns);
//CONFIG MODE END



//MQTT CONNECTING START
const char* mqtt_server = "broker.hivemq.com";
const char* message = "Door+ welcome";

void callback(char* topic, byte* message, unsigned int length) {
  
  
  
  String messageTemp;
  Serial.println(messageTemp);
  for (int i = 0; i < length; i++) {
    messageTemp += (char)message[i];
  }
  Serial.println(messageTemp);
  if (messageTemp != "[]") {
    
    
    surface = messageTemp;
    
    int delimiter = surface.indexOf("x");
    int delimiter_1 = surface.indexOf("x", delimiter + 1);
    int delimiter_2 = surface.indexOf("x", delimiter_1 +1);
    

    // Define variables to be executed on the code later by collecting information from the readString as substrings.
    String first = surface.substring(delimiter + 1, delimiter_1);
    String second = surface.substring(delimiter_1 + 1, delimiter_2);
    surface_room = first.toInt() * second.toInt();

    
    
    
  
  }
}


WiFiClient espClient; 
PubSubClient client(mqtt_server, 1833, callback, espClient);




void reconnect() {
  // Loop until we're reconnected
  while (!client.connected()) {
    Serial.print("Attempting MQTT connection...");
  
    // Attempt to connect
    if (client.connect("door_plus")) {
      Serial.println("connected");
      client.subscribe(topic1);
      client.subscribe(topic2);
    }
      
    else {
      Serial.print("failed, rc=");
      Serial.print(client.state());
      Serial.println(" try again in 5 seconds");
    // Wait 5 seconds before retrying  
      delay(5000);
    }
  }
}


//MQTT CONNECTING END




//przekazniki i czujniki odleglosci
const byte relay_open = 14; //pin przekaźnika
const byte relay_close = 16;
const byte TRIG1=5; // pin podłączony do pinu TRIG czujnika odlegosci 1
const byte TRIG2=23;
const byte ECHO1=13; // pin podlaczony do pinu ECHO czujnika odlegosci 1 //dlatego const byte zamiast define
const byte ECHO2=19;




//Funkcje globalne

float distance_meter(byte trig, byte echo) { //mierzenie odleglosci od czujnika
  unsigned long time;
  digitalWrite(trig, HIGH);
  delayMicroseconds(10);
  digitalWrite(trig, LOW);
  time = pulseIn(echo, HIGH);
  return time / 58.00;

}



void open_door() {
  
  for(axis = 0; axis<60; axis++){
    digitalWrite(relay_open, LOW);
    delay(100);
   
  }
 
  digitalWrite(relay_open, HIGH);
  axis = 0;
  isOpen = true;


}

void close_door() {
  for(axis = 0; axis<80; axis++){
    digitalWrite(relay_close, LOW);
    delay(100);
  

  }
  
  digitalWrite(relay_close, HIGH);
  axis = 0;
  isOpen = false ;

}

void motion_sensor(const byte trig_number, const byte echo_number){ //reaction for detected thing
  if (distance_meter(trig_number, echo_number)<=default_distance) //sprwadza czy odlegosc jest mniejsza rowna zmiennej default_distance
  {
    if(isOpen==false){
      open_door();
    }
    else {
      close_door();
    }
  }
  
 
 
  delay(500);
}






//main part of code:

//main part of code:

void setup() { /////////////////////////////////////////////SETUP
  Serial.begin(115200); //Ustawienie baud-rate



  if (!client.connected()){
    status_mqtt="OK";
  }
  else {
    status_mqtt="?";
  }
  
//DEFINICJE PINOW START
  
  pinMode(TRIG1, OUTPUT);
  pinMode(TRIG2, OUTPUT);
  pinMode(ECHO1, INPUT);
  pinMode(ECHO2, INPUT);
  pinMode(relay_open, OUTPUT);
  pinMode(relay_close, OUTPUT);


  digitalWrite(relay_open, HIGH);
  digitalWrite(relay_close, LOW);
  delay(10000);
  digitalWrite(relay_close, HIGH);
  isOpen=false;
//DEFINICJE PINOW END


  

//OLED START
  // Inicjalizacja wyświetlacza.
  if(!ekranik.begin(SSD1306_SWITCHCAPVCC, 0x3C)) {
      Serial.println("Błąd inicjalizacji wyświetlacza!");
      exit(0); // Nie idź dalej.
  }
  // Domyślny kolor tekstu: jasny na ciemnym tle.
  ekranik.setTextColor(WHITE);
  // Użyj 8-bitowego kodowania CP437, pozwalającego korzystać
  // ze wszystkich 256 znaków ASCII.
  ekranik.cp437(true);

  
 
//OLED END
  
  
//CONFIG START
  AsyncWiFiManager wifiManager(&server,&dns);

  wifiManager.autoConnect("Door+", "1234");
  Serial.println("connected...yeey :)"); 
  
  
  client.setServer(mqtt_server, 1883);
  client.setCallback(callback);
  Serial.println("Connected to MQTT");
  
//CONFIG END

  client.subscribe(topic1, 1); //topic subscribing
  client.subscribe(topic2,1);
}




void loop() {/////////////////////////////////////////////LOOP
  
//OLED START
  
  // Wyczyść bufor wyświetlacza przed zapisem do niego nowej treści.
  ekranik.clearDisplay();
  // Użyj najmniejszej czcionki.
  ekranik.drawLine(0, 13, 128, 16, WHITE);
  ekranik.drawLine(0,43,128,47,WHITE);
  
  
  ekranik.setTextSize(1);
 
 
  ekranik.setCursor(0, 0);
  ekranik.print("DOOR+");
  ekranik.setCursor(50, 0);
  

  ekranik.print("M: "+ status_mqtt);
  ekranik.setCursor(90, 0);
  ekranik.print("W: OK");
  ekranik.setCursor(0,48);
  ekranik.print("Surface:"+ String(surface_room));
  
  ekranik.setCursor(80, 48);
  ekranik.print("Pm2/: 1");

  ekranik.setTextSize(1.5);
  ekranik.setCursor(48,28);
  ekranik.print(String(people_room) + "/" + String(surface_room));

  
  ekranik.display();
  //delay(250);
//OLED END
  
  
  client.loop();
  delay(10);
  //mqtt connecting
  if (!client.connected()) {
    reconnect();
  }
  //mqtt connecting end
  
  

  
  //motion sensor 
  motion_sensor(TRIG1, ECHO1);
  motion_sensor(TRIG2,ECHO2);
  

  
}
